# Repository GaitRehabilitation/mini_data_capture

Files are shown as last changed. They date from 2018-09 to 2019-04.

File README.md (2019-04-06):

# Mini Data Capture

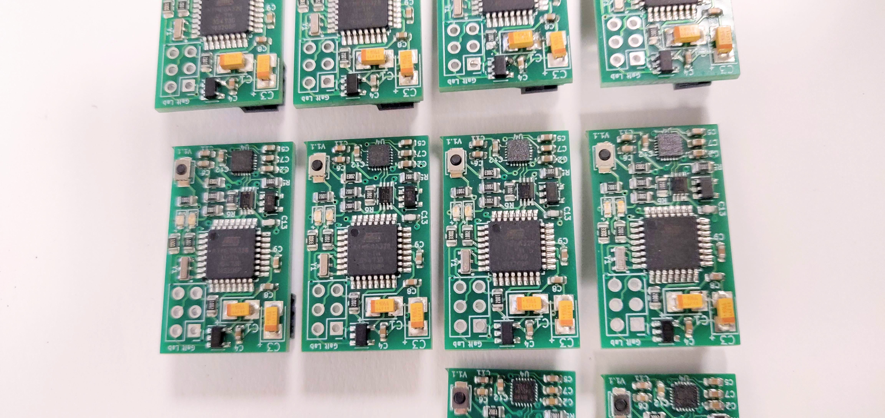
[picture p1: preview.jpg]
preview




## Programming

```avrdude -c <programmer> -p atmega328 -b 57600  -U flash:w:main.hex -U lfuse:w:0xff:m -U hfuse:w:0xd1:m -U efuse:w:0xff:m```

![avr fuse](./fuse_bits.png)

[Fuse Calculator](http://eleccelerator.com/fusecalc/fusecalc.php?chip=atmega328p)

## Maintainers

The current maintainers of this repository are:

* Michael Pollind <polli104@mail.chapman.edu>

# License

```
/**
* Copyright 2018 GaitRehabilitation
*
* Licensed under the Apache License, Version 2.0 (the "License");
* you may not use this file except in compliance with the License.
* You may obtain a copy of the License at
*
*     http://www.apache.org/licenses/LICENSE-2.0
*
* Unless required by applicable law or agreed to in writing, software
* distributed under the License is distributed on an "AS IS" BASIS,
* WITHOUT WARRANTIES OR CONDITIONS OF ANY KIND, either express or implied.
* See the License for the specific language governing permissions and
* limitations under the License.
*/

```

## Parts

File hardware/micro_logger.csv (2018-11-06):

Designator | MPN | Qty | Link
R2,R1,R6,R5 | 301010361 | 4
U2 | TLV70218DBVT | 1 | https://www.mouser.com/ProductDetail/Texas-Instruments/TLV70218DBVT
U4 | ICM-20948 | 1 | https://www.mouser.com/ProductDetail/TDK-InvenSense/ICM-20948
R4,R9,R3 | 301010361 | 3
C12,C11,C6,C5,C4 | 302010138 | 5
C7,C2 | 302010139 | 2
D3 | APT1608VBC/D | 1 | https://www.digikey.com/product-detail/en/kingbright/APT1608VBC-D/754-1789-1-ND/4753613
Y1 | CSTNE8M00G550000R0 | 1 | https://www.mouser.com/ProductDetail/Murata-Electronics/CSTNE8M00G550000R0
U3 | ATMEGA328-AU | 1 | https://www.mouser.com/ProductDetail/Microchip-Technology-Atmel/ATMEGA328-AU
U1 | MIC5205-3.3YM5-TR | 1 | https://www.mouser.com/ProductDetail/Microchip-Technology-Micrel/MIC5205-33YM5-TR
SW2 | B3U-1000P | 1 | https://www.digikey.com/product-detail/en/omron-electronics-inc-emc-div/B3U-1000P/SW1020CT-ND/1534357
R8 | 301010364 | 1
J5 | DM3AT-SF-PEJM5 | 1 | https://www.digikey.com/product-detail/en/DM3AT-SF-PEJM5/HR1964CT-ND/2533566
D1 | APT1608SGC | 1 | https://www.mouser.com/ProductDetail/Kingbright/APT1608SGC?qs=JpELLRhtMc0UatanJWL9tA%3D%3D
C9,C8 | 302010138 | 2
C3 | 302020011 | 1
C1 | 302020011 | 1
C13 | 302010076 | 1
R7 | 301010863 | 1
U5 | PCA9306DCUR | 1 | https://www.mouser.com/ProductDetail/Texas-Instruments/PCA9306DCUR

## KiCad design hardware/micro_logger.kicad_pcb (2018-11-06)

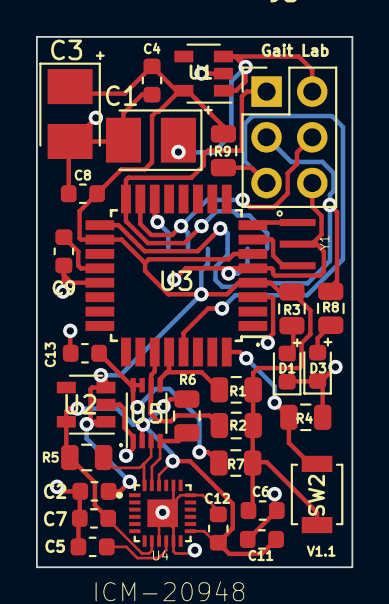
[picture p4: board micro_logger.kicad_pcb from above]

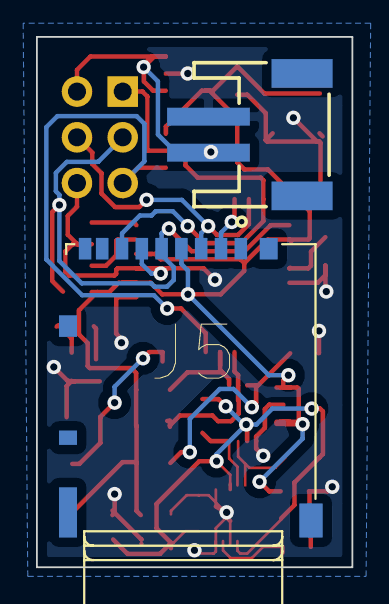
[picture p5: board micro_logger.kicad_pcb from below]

Board: 2 copper layers, 17.5 x 29.5 mm, 33 parts (2 on the bottom side), 21 nets.

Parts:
C1: 10uF; CP_Tantalum_Case-T_EIA-3528-12_Reflow
C2, C7: 1uF; C_0603_1608Metric
C3: 10uF; CP_Tantalum_Case-B_EIA-3528-21_Reflow
C4, C5, C6, C11, C12: .1uF; C_0603_1608Metric
C8, C9: .1uf; C_0603_1608Metric
C13: 100pF; C_0603_1608Metric
D1: LED; LED_0603_1608Metric
D3: LD271; LED_0603_1608Metric
J3: ISP; PinHeader_2x03_P2.54mm_Vertical
J4: Conn_01x02; JSTPH2
J5: DM3AT-SF-PEJM5; HRS_DM3AT-SF-PEJM5
R1, R2, R5, R6: 10K; R_0805_2012Metric
R3, R4, R9: 10k; R_0805_2012Metric
R7: 200K; R_0805_2012Metric
R8: 330; R_0805_2012Metric
SW2: SW_Push; SW_SPST_B3U-1000P
U1: MIC5205-3.3; SOT-23-5
U2: TLV70218_SOT23-5; SOT-23-5
U3: ATMEGA328-AU; TQFP-32_7x7mm_P0.8mm
U4: ICM-20948
U5: PCA9306; VSSOP-8_2.3x2mm_P0.5mm
Y1: Crystal_GND2; OSC_CSTCE8M00G55-R0

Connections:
+1V8: C7.1, C11.2, C12.2, R5.1, R6.1, U2.5, U4.8, U4.13, U4.22, U5.2
+3V3: C2.1, C3.1, C4.1, C6.1, C8.1, J5.4, R1.1, R2.1, R3.2, R7.2, R9.1, SW2.2, U1.5, U2.1, U2.3, U3.4, U3.6, U3.18
/Ardunio/D2: R4.2, SW2.1, U3.32
/Ardunio/RESET: J3.5, R9.2, U3.29
CS: J5.2, U3.14
GND: C1.2, C2.2, C3.2, C4.2, C5.1, C6.2, C7.2, C8.2, C9.2, C11.1, C12.1, C13.2, D1.1, D3.1, J3.6, J4.1, J5.6, R4.1, U1.2, U2.2, U3.3, U3.5, U3.21, U4.9, U4.11, U4.18, U4.20, U4.25, U5.1, Y1.2
MISO: J3.1, J5.7, U3.16
MOSI: J3.4, J5.3, U3.15
unnamed: C5.2, U4.10
unnamed: C9.1, U3.20
unnamed: C13.1, R7.1, U5.7, U5.8
unnamed: D1.2, R3.1
unnamed: D3.2, R8.1
unnamed: R5.2, U4.24, U5.3
unnamed: R6.2, U4.23, U5.4
unnamed: U3.7, Y1.3
unnamed: U3.8, Y1.1
SCK: J3.3, J5.5, R8.2, U3.17
SCL_MPU: R1.2, U3.28, U5.5
SDA_MPU: R2.2, U3.27, U5.6
VCC: C1.1, J3.2, J4.2, U1.1, U1.3

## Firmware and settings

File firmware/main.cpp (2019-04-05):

#include "Arduino.h"

#include <Wire.h>
#include <SPI.h>
#include <SdFat.h>

const int MPU_addr = 0x68;        // I2C address of the MPU-6050
const int LOGGING_BUTTON_PIN = 2; // logger button
const int CHIP_SELECT_PIN = 10;   // SD chip select

// 500Hz capture rate
const uint32_t LOG_INTERVAL_USEC = 2000; // intervals between data capture 1/(LOG_INTERVAL_USEC * .000001) = Sample rate in Hz

// number of blocks to queue before each write cycle
const uint8_t BUFFER_BLOCK_COUNT = 10;

// number of blocks to allocate for an empty file
const uint32_t FILE_BLOCK_COUNT = 256000;

char fileName[13];
int loggingButton = 0;
volatile bool wakeUpFlag = false;

SdFat sd;
SdBaseFile binFile;

const uint8_t ACCEL_DIM = 3;
const uint8_t GYRO_DIM = 3;
struct data_t
{
    uint32_t time;
    int16_t accel[ACCEL_DIM];
    int16_t gyro[GYRO_DIM];
    int16_t temp;
};

// Number of data records in a block.
const uint16_t DATA_DIM = (512 - 4) / sizeof(data_t);

// Compute fill so block size is 512 bytes.  FILL_DIM may be zero.
const uint16_t FILL_DIM = 512 - 4 - DATA_DIM * sizeof(data_t);

// a block of data for each chunk in the SD card 512 bytes
struct block_t
{
    uint16_t count;
    uint16_t overrun;
    data_t data[DATA_DIM];
    uint8_t fill[FILL_DIM]; 
};

void setup();
void wakupInterrupt();
void processorSleep();
void acquireData(data_t *data);
void createBin();
void configureMPU();
bool recordBinData();

void setup()
{
    Wire.begin();
    pinMode(LOGGING_BUTTON_PIN, INPUT);
    processorSleep();
}

void wakupInterrupt() // here the interrupt is handled after wakeup
{
    wakeUpFlag = true;
}

/**
* place the processor to sleep and also disable the IMU
**/
void processorSleep()
{
    Wire.beginTransmission(MPU_addr);
    Wire.write(0x06);
    Wire.write(B01000000); // set to mpu to sleep to avoid consuming power
    Wire.endTransmission(true);

    set_sleep_mode(SLEEP_MODE_PWR_DOWN);                                                // sleep mode is set here
    sleep_enable();                                                                     // enable sleep
    attachInterrupt(digitalPinToInterrupt(LOGGING_BUTTON_PIN), wakupInterrupt, RISING); // set wakeup flag when button is pressed
    sleep_mode();                                                                       // put processor to sleep
    sleep_disable();                                                                    // disable sleep
    detachInterrupt(digitalPinToInterrupt(LOGGING_BUTTON_PIN));                         // disables interrupt 0 on pin 2 to avoid setting flag
    delay(1000);
}

void createBin()
{
    // max number of blocks to erase per erase call
    const uint32_t ERASE_SIZE = 262144L;
    uint32_t bgnBlock, endBlock;

    // begin capture and set stream to 50Mhz
    if (!sd.begin(CHIP_SELECT_PIN, SD_SCK_MHZ(50)))
    {
        processorSleep();
    }
    else
    {
        int count = 0;
        while (true)
        {
            //set filename
            sprintf_P(fileName, PSTR("LOG%05u.BIN"), count);
            if (count > 65533) //There is a max of 65534 logs
            {
                break;
            }
            if (!sd.exists(fileName))
            {
                // create a new bin file if exsists
                binFile.close();
                if (!binFile.createContiguous(fileName, 512 * FILE_BLOCK_COUNT))
                {
                    break;
                }

                // Get the address of the file on the SD.
                if (!binFile.contiguousRange(&bgnBlock, &endBlock))
                {
                    break;
                }

                // Flash erase all data in the file.
                uint32_t bgnErase = bgnBlock;
                uint32_t endErase;
                while (bgnErase < endBlock)
                {
                    endErase = bgnErase + ERASE_SIZE;
                    if (endErase > endBlock)
                    {
                        endErase = endBlock;
                    }
                    if (!sd.card()->erase(bgnErase, endErase))
                    {
                        break;
                    }
                    bgnErase = endErase + 1;
                }

                break;
            }
            count++;
        }
    }
}

void configureMPU()
{
    Wire.beginTransmission(MPU_addr);
    Wire.write(0x06); // PWR_MGMT_1 register
    Wire.write(0);    // set to zero (wakes up the MPU-6050)
    Wire.endTransmission(true);

    Wire.beginTransmission(MPU_addr);
    Wire.write(0x7F);
    Wire.write(B00100000); //SELECT BANK 2
    Wire.endTransmission(true);

    Wire.beginTransmission(MPU_addr);
    Wire.write(0x14);
    Wire.write(B0000010); //sensitivity (4g here)
    Wire.endTransmission(true);

    Wire.beginTransmission(MPU_addr);
    Wire.write(0x01);
    Wire.write(B00000100); //here is the byte for sensitivity (1000 degree sec)
    Wire.endTransmission(true);

    Wire.beginTransmission(MPU_addr);
    Wire.write(0x7F);
    Wire.write(0); //SELECT BANK 0
    Wire.endTransmission(true);
}

void loop()
{
    if (wakeUpFlag)
    {

        createBin();
        configureMPU();
        wakeUpFlag = false;
    }
    else
    {
        while (recordBinData())
        {
        };
        processorSleep();
    }
}

bool recordBinData()
{

    const uint8_t QUEUE_DIM = BUFFER_BLOCK_COUNT + 1;
    // Index of last queue location.
    const uint8_t QUEUE_LAST = QUEUE_DIM - 1;

    // Allocate extra buffer space.
    block_t block[BUFFER_BLOCK_COUNT - 1];

    block_t *curBlock = 0;

    block_t *emptyStack[BUFFER_BLOCK_COUNT];
    uint8_t emptyTop;
    uint8_t minTop;

    block_t *fullQueue[QUEUE_DIM];
    uint8_t fullHead = 0;
    uint8_t fullTail = 0;

    // use the first block for the sdfat library
    emptyStack[0] = (block_t *)sd.vol()->cacheClear();
    if (emptyStack[0] == 0)
    {
        return false;
    }

    // Put rest of buffers on the empty stack.
    for (int i = 1; i < BUFFER_BLOCK_COUNT; i++)
    {
        emptyStack[i] = &block[i - 1];
    }
    emptyTop = BUFFER_BLOCK_COUNT;
    minTop = BUFFER_BLOCK_COUNT;

    // Start a multiple block write.
    if (!sd.card()->writeStart(binFile.firstBlock()))
    {
        return false;
    }

    bool closeFile = false;
    uint32_t bn = 0;
    uint32_t maxLatency = 0;
    uint32_t overrun = 0;
    uint32_t logTime = micros();
    while (1)
    {
        // Time for next data record.
        logTime += LOG_INTERVAL_USEC;

        //check if logging button is pressed again
        loggingButton = digitalRead(LOGGING_BUTTON_PIN);
        if (loggingButton == HIGH)
        {
            closeFile = true;
        }

        if (closeFile)
        {
            if (curBlock != 0)
            {
                fullQueue[fullHead] = curBlock; // Put buffer in full queue.
                fullHead = fullHead < QUEUE_LAST ? fullHead + 1 : 0; // Move head forward in the buffer
                curBlock = 0;
            }
        }
        else
        {
            if (curBlock == 0 && emptyTop != 0)
            {
                curBlock = emptyStack[--emptyTop];
                if (emptyTop < minTop)
                {
                    minTop = emptyTop;
                }
                curBlock->count = 0;
                curBlock->overrun = overrun;
                overrun = 0;
            }
            int32_t delta;
            do
            {
                delta = micros() - logTime;
            } while (delta < 0);
            if (curBlock != 0)
            {
                // write entry into the current block
                acquireData(&curBlock->data[curBlock->count++]);
                // if the block is full then move it to the queue and and move the head forward 
                if (curBlock->count == DATA_DIM)
                {
                    fullQueue[fullHead] = curBlock;
                    fullHead = fullHead < QUEUE_LAST ? fullHead + 1 : 0;
                    curBlock = 0;
                }
            }
        }
        if (fullHead == fullTail)
        {
            // Exit loop if done.
            if (closeFile)
            {
                break;
            }
        }
        else if (!sd.card()->isBusy())
        {
            // Get address of block to write.
            block_t *pBlock = fullQueue[fullTail];
            fullTail = fullTail < QUEUE_LAST ? fullTail + 1 : 0;
            // Write block to SD.
            uint32_t usec = micros();
            if (!sd.card()->writeData((uint8_t *)pBlock))
            {
                break;
            }
            usec = micros() - usec;
            if (usec > maxLatency)
            {
                maxLatency = usec;
            }
            // Move block to empty queue.
            emptyStack[emptyTop++] = pBlock;
            bn++;
            if (bn == FILE_BLOCK_COUNT)
            {
                createBin();
                return true;
            }
        }
    }
    return false;
}

void acquireData(data_t *data)
{
    Wire.beginTransmission(MPU_addr);
    Wire.write(0x2D); // starting with register 0x2D (ACCEL_XOUT_H)
    Wire.endTransmission(false);
    Wire.requestFrom(MPU_addr, 14, true);            // request a total of 14 registers
    data->accel[0] = Wire.read() << 8 | Wire.read(); // 0x2D (ACCEL_XOUT_H) & 0x3C (ACCEL_XOUT_L)
    data->accel[1] = Wire.read() << 8 | Wire.read(); // 0x2F (ACCEL_YOUT_H) a& 0x3E (ACCEL_YOUT_L)
    data->accel[2] = Wire.read() << 8 | Wire.read(); // 0x31 (ACCEL_ZOUT_H) & 0x40 (ACCEL_ZOUT_L)
    data->gyro[0] = Wire.read() << 8 | Wire.read();  // 0x33 (GYRO_XOUT_H) & 0x44 (GYRO_XOUT_L)
    data->gyro[1] = Wire.read() << 8 | Wire.read();  // 0x35 (GYRO_YOUT_H) & 0x46 (GYRO_YOUT_L)
    data->gyro[2] = Wire.read() << 8 | Wire.read();  // 0x37 (GYRO_ZOUT_H) & 0x48 (GYRO_ZOUT_L)
    data->temp = Wire.read() << 8 | Wire.read();     // 0x39 (TEMP_OUT_H) & 0x42 (TEMP_OUT_L)
    data->time = micros();                           // set time
}

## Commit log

2018-09-30 adjusted layout
    [micro_logger.kicad_pcb]
2018-09-30 cleaned up layout
    [micro_logger.kicad_pcb]
2018-09-30 added gait logo
    [micro_logger.kicad_pcb]
2018-09-30 updated border
    [micro_logger.kicad_pcb]
2018-10-01 updated layout
    [micro_logger.kicad_pcb]
2018-10-01 hid elements
    [micro_logger.kicad_pcb]
2018-10-19 updated shift logic
    [Ardunio.sch, micro_logger.kicad_pcb]
2018-10-24 re-organized file structure
    [Ardunio.sch, ardunio.sch, micro_logger.kicad_pcb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]
2018-10-31 merged in firmware
    [micro_logger.sch]
2018-11-06 added bom
    [micro_logger.csv]
2018-11-06 updated symbols
    [micro_logger.kicad_pcb]
2018-11-17 updated schematic
    [Ardunio.sch, micro_logger.sch]
2018-11-17 removed unused sheet
    [Ardunio.sch, micro_logger.sch]
2019-01-12 fixed overwrite file condition
    [main.cpp]
2019-01-22 added decoding app
    [Ardunio.sch, micro_logger.sch]
2019-03-08 moved thread implementation
2019-03-11 fixed threading issue
    [ardunio.sch]
2019-04-05 updated documentation
    [Ardunio.sch, micro_logger.sch]
2019-04-06 added fuse configurations
2019-04-06 added link to fuse calculator
